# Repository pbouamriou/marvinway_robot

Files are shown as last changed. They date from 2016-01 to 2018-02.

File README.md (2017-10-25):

# marvinway
Source du projet Marvin Way (le segway depressif O_o)

## Arborescence ##

### brain ###

Projet de la carte de contrôle Haut niveau de Marvin

### control

Projet pour la carte de contrôle des moteurs

### docs

Contient la documentation globale du projet

### experience

Contient les exemples des expériences associés au projet marvinway

### meca

Contient la conception mecanique de Marvin

### shield

Projet permettant la communication entre le Brain et le reste du monde (la moelle epinière en soit)

### supply

Projet de gestion de l'alimentation

### utils

Contient des librairies utils ou des ensembles de configurations

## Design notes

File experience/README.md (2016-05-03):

# marvinway
Source du projet Marvin Way (le segway depressif O_o)

## Programme de test ##

### Installation de la chaine de compilation Teensy ###

Suivre les instructions [Débuter avec teensy](https://openclassrooms.com/courses/debuter-dans-l-informatique-embarquee-avec-teensy).

Installer tout de meme la toolchain Arduino dans le répertoire /opt car ça permettra à cmake de trouver automatiquement la toolchain.

### Installation de teensy_loader_cli

Pour permettre à cmake d'installer votre programme sur la teensy

Executez simplement les commandes suivantes depuis le dépot marvin

_Installation de teensy_loader_cli
~~~{.sh}
cd src/teensyLoaderCli/
chmod 755 teensyLoaderCli.sh # si nécéssaire
./teensyLoaderCli.sh
~~~

### Compilation ###

_Compilation du programme de test blink sous linux_

~~~{.sh}
cd src/test_blink
./configure
(cd build && cmake )
~~~

Voila c'est compilé, un fichier blink.hex est disponible sous build/blink

il est meme possible de produire et installer le programme grâce à cmake (programme test_blink par example) :

~~~{.sh}
cd src/test_blink
./configure
(cd build && cmake blink-upload )
~~~

### Test du programme ###

Suivre les memes instructions décrites par le site [Débuter avec teensy](https://openclassrooms.com/courses/debuter-dans-l-informatique-embarquee-avec-teensy).

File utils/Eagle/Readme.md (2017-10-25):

# Configuration de Eagle

## Ajouter une librairie

- Aller dans le `Control Panel -> Directories`
   ControlPanel
- Dans le premier champ ajouter le répertoire où se trouve les librairies
  (Le répertoire Libs contient des exemples de librairies utilisées dans des projets de Marvin)
- Pour Utiliser la librairie dans Eagle 
  - Il faut l'activer en affichant la liste `Libraries`

  - Cliquez droit sur la librairie Sparkfun puis appuyez sur use all

    Utilisation d'une librairie

## Configurer l'interface de création de la carte

Depuis l'interface de création de carte (board)  cliquez sur l'icones de script scr puis chargez le fichiers ConfigurationScript/spk.scr

## Informations Utiles

### Design Rule Check

Pour vérifier que la carte conçu respecte les bonnes pratiques de l'imprimeur il faut utiliser les Design Rules du constructeur. Sparkfun fourni ses propres règles de design de cartes  vous pouvez les trouver dans le répertoire EagleDesignRules.

Pour charger les règles de design il faut appuyer sur l'icône DRC icon DRC icon une interface va apparaitre appuyer sur Load

DRC

### Synchronisation entre schéma et board

Pour conserver la synchronisation entre le fichier board et le fichier schematic penser à bien les garder ouvert en même temps

## Sources

https://github.com/sparkfun/SparkFun-Eagle-Libraries

https://learn.sparkfun.com/tutorials/how-to-install-and-setup-eagle

https://learn.sparkfun.com/tutorials/using-eagle-schematic

https://learn.sparkfun.com/tutorials/using-eagle-board-layout

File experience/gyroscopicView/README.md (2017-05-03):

# gyroscopic view  
Affiche une vue openGL simple représentant l'orientation du gyroscope en tant réell

## Installation de l'environnement

### Sur Debian

~~~{.sh}
sudo apt-get install cmake libgl1-mesa-dev libglu1-mesa-dev freeglut3-dev libxmu-dev libxi-dev doxygen libboost-dev python-pip python-empy
sudo pip install -U catkin_pkg
git clone https://gicd catkin/thub.com/ros/catkin.git
cd catkin && mkdir build && cd build && cmake ../ && make && sudo make install && cd ..
git clone https://github.com/wjwwood/serial.git && cd serial
make
make install
cd ..
~~~

## Branchement de la carte Arduino au MPU_6050

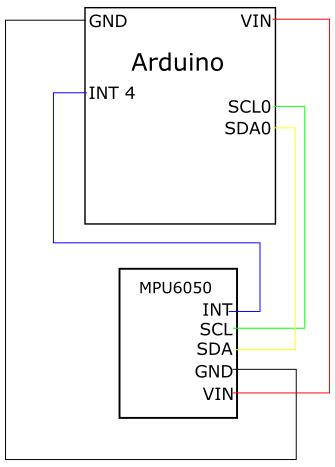
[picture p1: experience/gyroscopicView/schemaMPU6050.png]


## Calibrage du MPU_6050 ##

### Compilation et upload du programme de calibrage
~~~{.sh}
cd src/mpu6050/
make
cd build/MPU6050_Calibration/
make calibration-upload
~~~

Pensez à appuyer sur le bouton de votre arduino après le "make upload" pour bien uploader le programme

### Execution du programme de calibrage
Connectez vous au port série de la teensy pour qu'elle se calibre
Avant le calibrage vérifiez que le MPU6050 est bien à plat et ne touchez plus à la table

~~~{.sh}
cu -l /dev/ttyACM0 -s 9600
~~~
La calibration peut prendre un peu de temps.
une fois la calibration terminée reportez les valeurs dans le programme MPU6050_DOF

### Modification de l'offset dans MPU6050_DMP6
Modifier le fichier "MPU6050_DMP6/MPU6050_DMP6.ino" avec les valeurs suivantes qui se trouvent environ ligne 200
~~~{.cpp}
mpu.setXGyroOffset(27);                                                                                      
mpu.setYGyroOffset(7);
mpu.setZGyroOffset(2);
mpu.setZAccelOffset(1340); // 1688 factory default for my test chip
~~~

## Compilation et Upload du programme pour récupérer les angles d'eulers
~~~{.sh}
cd src/mpu6050
make
cd build/MPU6050_DMP6/
make mpu6050-upload
~~~

Pensez à appuyer sur le bouton de votre arduino après le "make upload" pour bien uploader le programme

## Compilation et lancement l'affichage gyroscopic

~~~{.sh}
cmake .
cd src/gyroscopicView
make
cd build/
./gyroscopicView
~~~

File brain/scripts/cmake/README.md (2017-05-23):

# Teensy CMake

## Informations
Cette toolchain est compatible avec Arduino 1.8.2 et teensyduino 1.36.

Ce projet est conçus pour être utilisé en tant que [sous module git](https://git-scm.com/book/fr/v2/Utilitaires-Git-Sous-modules) dans votre projet.

## Prérequis
### Installer Arduino 1.8.2
Vous devez installer [Arduino 1.8.2](https://git-scm.com/book/fr/v2/Utilitaires-Git-Sous-modules)
dans **/opt/arduino/** pour que le SDK arduino ainsi la toolchain pourra détecter le SDK arduino

Si vous ne savez pas comment installer Arduino je vous conseille de suivre cette [procédure] 
(https://www.hackster.io/strasserpatrick/install-arduino-ide-1-8-2-on-linux-8ef105) fonctionnelle sous debian 8

### Installer Teensyduino 1.36
Pour installer Teensyduino v1.36 suivre la procédure décrite sur le site de 
[teensy](https://www.pjrc.com/teensy/td_download.html)

### Compiler et Installer Teensyloader
Après avoir compilé le **teensyloader_cli** copier le dans **/opt/teensyloader_cli**
ainsi la toolchain pourra détecter le teensyloader_cli

Voici les [étapes](https://github.com/PaulStoffregen/teensy_loader_cli) pour compiler **teensy_loader_cli**

## Utilisation de Teensy CMake
- Créez votre projet git
- Ajouter ce dépot en tant que sous module 

```bash
git submodule add git@gitlab.42pillistreet.com:marvin/teensy_cmake.git
```

- Créez votre fichier CMakeLists.txt

```cmake
cmake_minimum_required(VERSION 2.8)
set(CMAKE_TOOLCHAIN_FILE "${CMAKE_SOURCE_DIR}/teensy_cmake/teensy-arm.toolchain.cmake")

project(blink C CXX)

macro(use_cxx11)
  if (CMAKE_VERSION VERSION_LESS "3.1")
    if (CMAKE_CXX_COMPILER_ID STREQUAL "GNU")
      set (CMAKE_CXX_FLAGS "--std=gnu++11 ${CMAKE_CXX_FLAGS}")
    endif ()
  else ()
    set (CMAKE_CXX_STANDARD 11)
  endif ()
endmacro(use_cxx11)

use_cxx11()

set(CMAKE_RUNTIME_OUTPUT_DIRECTORY "${CMAKE_CURRENT_BINARY_DIR}/bin")
set(CMAKE_ARCHIVE_OUTPUT_DIRECTORY "${CMAKE_CURRENT_BINARY_DIR}/lib")
set(CMAKE_LIBRARY_OUTPUT_DIRECTORY "${CMAKE_CURRENT_BINARY_DIR}/lib")
set(CMAKE_MODULE_PATH ${CMAKE_MODULE_PATH} ${CMAKE_CURRENT_SOURCE_DIR}/teensy_cmake)
set(TEENSY_USB_MODE SERIAL)
add_teensy_executable(blink blink.cpp)
configure_teensy_upload(blink mk20dx256) # you must specify the sane name than the executable mk20dx256 Teensy 3.1
```

- Voici le fichier blink.cpp d'exemple

```c++
/*
  Blink
  Turns on an LED on for one second, then off for one second, repeatedly.
  Example uses a static library to show off generate_arduino_library().
 
  This example code is in the public domain.
*/
#if ARDUINO >= 100
    #include "Arduino.h"
#else
    #include "WProgram.h"
#endif

const int led = LED_BUILTIN;

void setup() {                
  pinMode(led, OUTPUT);
}

void loop() {
  digitalWrite(led, HIGH);
  delay(1000);
  digitalWrite(led, LOW);
  delay(1000);
}
```

- Initialisez votre projet puis compilez le

```bash
mkdir build
cd build
cmake ..
make
make upload
```

- Maintenant appuyez sur le bouton reset de votre teensy et voilà ! :D

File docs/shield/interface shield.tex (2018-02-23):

\documentclass[11pt]{article}
\usepackage[utf8]{inputenc}
\usepackage[T1]{fontenc}
\usepackage[francais]{babel}
\usepackage{bytefield}

\begin{document}

\title{Interface MarvinShield}

\section{Introduction}

Le FPGA est piloté en SPI.

\section{Commandes}

Il existe deux types de commandes :
\begin{itemize}
  \item une commande de lecture d'une zone mémoire,
  \item une commande d'écriture d'une zone mémoire. 
\end{itemize}

La figure suivante présente le chronogramme d'une phase de lecture.

La figure suivante présente le chronogramme d'une phase d'écriture.

\subsection{Organisation mémoire}

La carte MarvinShield organise la mémoire de la manière suivante : \\

\begin{bytefield}[endianness=big, bitwidth=1em, leftcurly=., leftcurlyspace=0pt]{32}
\bitheader{0,7,8,15,16,23,24,31} \\
\begin{leftwordgroup}{00h}
\bitbox{32}{FPGA Magic ID}
\end{leftwordgroup} \\
\begin{rightwordgroup}{Version}
\begin{leftwordgroup}{04h}
\bitbox{8}{Reserved} \bitbox{8}{Majeur} \bitbox{8}{Mineur} 
& \bitbox{8}{Revision}
\end{leftwordgroup}
\end{rightwordgroup} \\
\begin{leftwordgroup}{08h}
\wordbox[tlr]{1}{}
\end{leftwordgroup} \\
\wordbox[lr]{2}{FPGA Desc} 	\\
\wordbox[blr]{1}{} \\
\begin{rightwordgroup}{Capabilities}	
\begin{leftwordgroup}{18h}
\bitbox{16}{Capability (1)} \bitbox{16}{Capability (2)}
\end{leftwordgroup} \\
\wordbox{6}{$\cdots$} \\
\begin{leftwordgroup}{38h}
\bitbox{16}{Capability (15)} \bitbox{16}{Capability (16)}
\end{leftwordgroup}
\end{rightwordgroup} \\
\begin{leftwordgroup}{3Ch}
\wordbox{1}{First device address}
\end{leftwordgroup}
\end{bytefield}

Tous les champs
Le champ "FPGA Magic ID" est toujours positionné par la shield  

\subsection{Capacités du FPGA}

\begin{bytefield}[endianness=little,bitwidth=2.2em]{16}
\bitheader{0-15} \\ 
\bitbox{3}{device ID} \bitbox{3}{device version} \bitbox{10}{Offset in memory} \\
\end{bytefield}

La liste des différents périphériques sont :
\begin{itemize}
\item PWM, valeur 01h
\item ADC, valeur 02h
\item GPIO, valeur 03h
\end{itemize}

Le champ "Offset in memory" défini l'adressage du périphérique à partir de l'adresse 3Ch.

\end{document}

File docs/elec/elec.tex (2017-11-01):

\documentclass[10pt,a4paper]{article}
\usepackage[utf8]{inputenc}
\usepackage[french]{babel}
\usepackage[T1]{fontenc}
\usepackage{amsmath,amsfonts,amssymb}
\usepackage[squaren, Gray, cdot]{SIunits}
\usepackage{tikz}
\usepackage{circuitikz}
\usepackage[left=2cm,right=2cm,top=2cm,bottom=2cm]{geometry}
\usepackage{url}

\tikzset{
xmin/.store in=\xmin, xmin/.default=-3, xmin=-3,
xmax/.store in=\xmax, xmax/.default=3, xmax=3,
ymin/.store in=\ymin, ymin/.default=-3, ymin=-3,
ymax/.store in=\ymax, ymax/.default=3, ymax=3,
}
% Commande qui trace la grille entre (xmin,ymin) et (xmax,ymax)
\newcommand {\grille}
{\draw[help lines] (\xmin,\ymin) grid (\xmax,\ymax);}
% Commande \axes
\newcommand {\axes} {
\draw[->] (\xmin,0) -- (\xmax,0);
\draw[->] (0,\ymin) -- (0,\ymax);
}
% Commande qui limite l'affichage à (xmin,ymin) et (xmax,ymax)
\newcommand {\fenetre}
{\clip (\xmin,\ymin) rectangle (\xmax,\ymax);} 
 
\begin{document}{\bf Cours d'electronique} 

\section{Circuit série et U=RI}
Dans un circuit la tension (U exprimée en \volt ) est égale à la résistance (R exprimée en \ohm) multiplié par l'intensité (I exprimée en \ampere) ce qui donne l'équation~\eqref{uri}
\begin{equation}
U=R*I
\label{uri}
\end{equation}

Remarque en série les résistances s'additionnent.

Prenons un circuit avec les résistances R1= 5 \ohm, R2= 20 \ohm, R3= 30 \ohm
\shorthandoff{:!}
\begin{figure}[h!]
  \begin{center}
    \begin{circuitikz}
      \draw (0,0)
      to[V,v=$U_q$] (0,2) % The voltage source
      to[R=$R_1$,v_<=$U_1$] (2,2) % R1
      to[R=$R_2$,v_<=$U_2$] (4,2) % R2
      to[R=$R_3$,v_<=$U_3$] (6,2) % R3
      to[short,i=$i$] (6,0)
      to[short] (0,0);
    \end{circuitikz}
    \caption{Circuit simple.}
  \end{center}
\end{figure}

Remarque en série les résistances s'additionnent.
\begin{align}
R_t &=R_1+R_2+R_3 \\
    &=5+20+30 \\
    &=55 \ohm
\end{align}

\begin{align}
I&=\frac{U}{R} \\
I&=\frac{12}{55} \\
I&=0,218 \ampere \\
\end{align}
La loi d'additivité des tensions se vérifie donc 
\begin{align}
U1&=5*0,218=1,09 \volt \\
U2&=20*0,218=4,36 \volt \\
U3&=30*0,218=6,54 \volt \\
U_q&=U1+U2+U3~=12 \volt
\end{align}

\pagebreak 

\section{Circuit Parellèle et Conductance}
La conductance est l'inverse de la résistance $ C= \frac{1}{Rt} $

\shorthandoff{:!}
\begin{figure}[h!]
  \begin{center}
    \begin{circuitikz}
      \draw (0,0)
      to[V,v=$U_q$] (0,5) % The voltage source
      to[short] (4,5)
      to[short,i_=$i_t$] (4,4)
      (4,4) to[short,i_=$i_1$] (3,4)
      to[short] (3,3)
      (4,4) to[short,i_=$i_2$] (5,4)
      to[short] (5,3)
      (3,3) to[R=$R_1$,v_<=$U_1$] (3,2) % R1
      to[short] (3,1)
      (5,3) to[R=$R_2$,v_<=$U_2$] (5,2) % R2
      to[short] (5,1)
      (3,1) to[short] (4,1)
      (5,1) to[short] (4,1)
      to[short] (4,0)
      to[short] (0,0);
    \end{circuitikz}
    \caption{Conductance d'un circuit parallèle.}
  \end{center}
\end{figure} 

R1 = 50 \ohm R2 = 30 \ohm

Pour ce circuit la conductance $ C = \frac{1}{R1}+\frac{1}{R2} = \frac{1}{50}+\frac{1}{30} = \frac{8}{150} $
Ce qui nous donne $R_t=\frac{150}{8} = 18,75 \ohm $ 

Ici on voit que la résistance totale de notre circuit parallèle est inférieur à la plus petite des résistances.

Si on calcule $i_1=\frac{U_1}{R_1}=\frac{12}{50}=0,24 \ampere $ $i_2=\frac{U_2}{R_2}=\frac{12}{30}=0,4 \ampere $

Si on compare a la résistance totale $I=\frac{12}{18,75}=0,64 \ampere$ nos deux intensités sont bien égales. 

\section{la Puissance}

La puissance P est exprimée en \watt elle se calcule à l'aide de la tension et de l'intensité utilisé par le circuit $P=U*I$.

\begin{figure}[h!]
  \begin{center}    
    \begin{circuitikz}
      \draw (0,0)
      to[V,v=$U_g$] (0,2) % The voltage source
      to[R=$R_i$,v_<=$U_i$] (2,2) % R1
      to[R=$R$,v_<=$U$] (2,0) % R2
      to[short] (0,0);
    \end{circuitikz}
    \caption{Voici mon radiateur.}
  \end{center}
\end{figure}

$R_i$ représente la résistance interne du générateur.    

$R_i=1 \ohm$ et $R = 20 \ohm$

Pour obtenir la puissace fournie par le générateur $P_f$ il faut calculer la somme des résistances $R_t= \sum R = R_i+R=1+20=21 \ohm$

avec $U=R \times I$ on peut déduire que $P=U \times I=R \times I^2=\frac{U^2}{R}$ 

on peut donc déduire directement la puissance fournie par le générateur en utilisant $P_f=\frac{U_g^2}{R}=\frac{12^2}{21}=6,857 \watt$

La puissance utile $P_u$ représente la puissance réellement utilisée est la puissance utilisé par la résistance. Pour cela il faut connaitre le courant utilisé par le circuit $I=\frac{U}{R_t}=\frac{12}{21}=0,571 \ampere$

ce qui nous donne $P_u =R \times I^2=20 \times 0,571^2=6,520 \watt$

on peut donc déduire le rendement de notre résistance $R=\frac{P_u}{P_f}=\frac{6,520}{6,857}=0,985$

\pagebreak

\section{Le condensateur}
Le condensateur est un composant qui se charge lorsqu'il est traversé par du courant jusqu'à ce qu'il ait atteint sa capacité maximal. La capicé d'un condensateur est exprimée en Farad (\farad).

Il est composé de lamelle et d'un espace vide entre elle
\begin{figure}[h!]
  \begin{center}
    \begin{circuitikz}
        \draw (0,0) 
        to node[below,pos=2]{$+q$} node[above,pos=2]{$+$} (0.5,0) 
        to [C, l^=$C$] (2.5,0) 
        to node[below,pos=-1]{$-q$} node[above,pos=-1]{$-$} (3,0) ;
    \end{circuitikz}
    \caption{Schéma d'un condensateur.}
  \end{center}
\end{figure}

Lorsque le courant $i_1$ traverse un condensateur les electrons s'accumulent sur lamelle représenté par $-q$ tandis que l'autre lamelle elle se débarrassent de ses électrons. Au fur et à mesure le courant décroit jusqu'à être nul. À ce moment notre condensateur à atteint sa pleine capacité. il va donc falloir le décharger pour pouvoir faire passer un nouveau courant.

\begin{figure}[h!]
  \begin{center}
    \begin{circuitikz}
        \draw (0,0)
        to[V,v=$U_g$] (0,2) % The voltage source
        to[short] (2,2)
        to[lamp] (4,2)
        to[C,v_<=$U_c$,i^>=$i_c$,l^=$C$] (4,0)
	to[short] (0,0)
	(2,2) to[short] (2,1); 
    \end{circuitikz}
    \caption{Circuit de charge.}
  \end{center}
\end{figure} 

Durant la charge la lampe va s'allumer puis l'intensité dans le circuit va décroite au fur et a mesure que le condensateur se charge.
Jusqu'à ce qu'elle s'éteigne une fois le condensateur complètement chargé. La tension du condensateur est alors maximal voir Figure~\ref{courbeCondensateur} p~\pageref{courbeCondensateur}
\begin{figure}[h!]
  \begin{center}
    \begin{circuitikz}
        \draw (0,0)
        to[V,v=$U_g$] (0,2) % The voltage source
        to[short] (2,2)
        to[lamp] (4,2)
        to[C,v_<=$U_c$,i_<=$i_c$,l^=$C$] (4,0)
        to[short] (2,0)
	(0,0) to[short] (1,0)
        (2,2) to[short] (2,0);
    \end{circuitikz}
    \caption{Circuit de décharge.}
  \end{center}
\end{figure}

Lors de la décharge on s'aperçoit que le courant est inversé voir Figure~\ref{courbeCondensateur} p~\pageref{courbeCondensateur}. Le phénomène est dû au fait que les électrons sont attirés par l'autre lamelle. lors de leur parcourt du circuit ils vont donc allumer la LED jusqu'à temps que le condensateur soit vide. 

Durant la décharge on observe que la tension du condensateur diminue Figure~\ref{courbeCondensateur} p~\pageref{courbeCondensateur}.
\begin{figure}
   \begin{center}
      \begin{tikzpicture}[xmin=0,xmax=16,ymin=-5,ymax=5]
   	  \axes
   	  %\draw [very thin, gray] (0,0) grid[step=0.2] (4.4,4.2);
   	  \draw[color=red] [domain=0:8, smooth] plot (\x,{4/(\x+1)-0.4});
   	  \draw[color=blue] [domain=0:8, smooth] plot (\x,{(4/(-\x-1)+4)});
          \draw[color=blue] [domain=8:16, smooth] plot (\x,{4/(\x-7)-0.4});
          \draw[color=red] [domain=8:16, smooth] plot (\x,{(4/(-\x+7)+0.4)});
	  \draw[color=blue] (0,5) node [right] {$U(\volt)$};
	  \draw[color=red] (0,5) node [left] {$I(\ampere)$};
   	  \draw (16,0) node [below] {t};
   	  \draw (0,0) node [below left] {O};
   	  \fill[color=green!70, opacity=0.5] (0,-0.1) rectangle (8,0.1);
   	  \draw (4,0) node [below] {$charge$};
	  \fill[color=yellow!70, opacity=0.5] (8,-0.1) rectangle (16,0.1);
          \draw (12,0) node [below] {$decharge$};
       \end{tikzpicture}
       \caption{Courbe d'intensité de charge}
       \label{courbeCondensateur}
   \end{center}
\end{figure} 

\section{Le transistor MOFSET}

Le Mofset est un transistor différent du transistor bipolaire car il est piloté en tension (le bipolaire étant piloté en courant). De plus le transistor MOFSET
consomme peu d'énergie (du moins quand il est pas sans cesse en commutation).
En mode non commuté, il se comporte comme une résistance variable.

Le transistor MOFSET existe en 4 déclinaisons :
\begin{itemize}
  \item Le MOFSET à canal N à enrichissement (Figure \ref{mofsetNenri}). Lorsque la tension $V_{TH}$ est suppérieure au seuil $V_{TH}$, le MOFSET est passant.
  \item Le MOFSET à canal P à enrichissement (Figure \ref{mofsetPenri}). Lorsque la tension $V_{TH}$ est inférieure au seuil $V_{TH}$ ($V_{TH}$ étant une tension négative), le MOFSET est passant.
  \item Le MOFSET à canal N à appauvrissement (Figure \ref{mofsetNappau}). Lorsque la tension $V_{TH}$ est inférieur au seuil $V_{TH}$, le MOFSET est passant.
  \item Le MOFSET à canal P à appauvrissement (Figure \ref{mofsetPappau}). Lorsque la tension $V_{TH}$ est suppérieure au seuil $V_{TH}$ ($V_{TH}$ étant une tension négative), le MOFSET est passant.
\end{itemize}

\begin{figure}
   \begin{center}
      \begin{circuitikz}
      % Equivalent circuit:
         \begin{scope}[scale=0.8]
            \draw (0,0) to[Tnigfete,n=mosn] (0,2);
         \end{scope}
      \end{circuitikz}
      \caption{Mofset à canal N à enrichissement}
      \label{mofsetNenri}
   \end{center}
\end{figure}

\begin{figure}
   \begin{center}
      \begin{circuitikz}
      % Equivalent circuit:
         \begin{scope}[scale=0.8]
            \draw (0,0) to[Tpigfete,n=mosp] (0,2);
         \end{scope}
      \end{circuitikz}
      \caption{Mofset à canal P à enrichissement}
      \label{mofsetPenri}
   \end{center}
\end{figure}

\begin{figure}
   \begin{center}
      \begin{circuitikz}
      % Equivalent circuit:
         \begin{scope}[scale=0.8]
            \draw (0,0) to[Tnigbt,n=mosn] (0,2);
         \end{scope}
      \end{circuitikz}
      \caption{Mofset à canal N à appauvrissement}
      \label{mofsetNappau}
   \end{center}
\end{figure}

\begin{figure}
   \begin{center}
      \begin{circuitikz}
      % Equivalent circuit:
         \begin{scope}[scale=0.8]
            \draw (0,0) to[Tpigbt,n=mosp] (0,2);
         \end{scope}
      \end{circuitikz}
      \caption{Mofset à canal P à appauvrissement}
      \label{mofsetPappau}
   \end{center}
\end{figure}

Les MOFSETS sont souvent utilisés pour commuter des circuits de plusieurs ampères. On nomme ces MOFSETS, MOFSETS de puissance.
Malheureusement ces MOFSETS ne sont pas totallement adaptés aux micro-controlleurs, car les niveaux logiques des micro-controlleurs sont plus bas que ceux des MOFSETS
de puissance. Cela à pour conséquence, de ne pas faire fonctionner le MOFSET en mode commuté. Ainsi, la résistance aux bornes du MOFSET ($RDS_{on}$) n'est pas au plus bas.

C'est pour cette raison qu'une famille de MOFSET a été créer pour s'adapter aux niveaux logiques des micro-controlleurs. Cette famille se nomme «logic level».

Une autre problématique avec les transistors MOFSETS est de permettre une commutation rapide à hautes fréquences (au delà de 20kHz). Il s'avère qu'une commutation rapide
n'est possible que lorsque le circuit de commande fourni suffisement de courant pour «accélérer la commutation». Bien souvent les circuits de commande sont des
micro-controlleurs qui ne permettent pas fournir le courant demandé par le transistor. La commutation est alors ralenti.

Le schéma \ref{driverInverseur} présente le moyen de piloter un mofset mais avec une logique inverse. L'avantage de ce schéma est d'etre beaucoup plus simple à comprendre.

\begin{figure}
   \begin{center}
      \begin{circuitikz}
      % Equivalent circuit:
         \begin{scope}[scale=0.8]
            \draw
            (0,0) node[left]{PWM} to[short,o-](1,0)
            to[R,l=R1] (3,0)
            to[short] (4,0)
            to node[pnp,anchor=B]{} (5,0);
         \end{scope}
      \end{circuitikz}
      \caption{Driver de MOFSET en mode inverseur}
      \label{driverInverseur}
   \end{center}
\end{figure}

\section{Les Bobines}

Les bobines (appelées aussi autoinductances, solénoïde ou self) est constitué d'un enroulement de fil conducteur éventuellement autour d'un noyau en matériau férromagnétique \cite{BobineWiki}.

à compléter
- Pilotage de courant 
- Filtre

\section{les moteurs}
\subsection{Introduction}

Il existe différents types de moteur (thermique, electrique, stirling...), cette section va se concentrer sur les moteur électriques plus précisément les moteurs à courant continu.

Un moteur permet de transformer l'énergie électrique en énergie mécanique. l'avantage du moteur électrique par rapport a un moteur thermique est que sont rendement est bien meilleur (de l'ordre de 80% pour un moteur électrique contre 40%). Cependant malgré un très bon rendement  

\subsection{À quoi ça sert un moteur ?}

Il s'agit d'un composant de \textbf{conversion d'énergie électrique en énergie mécanique de rotation}. A contrario une dynamo fonctionne sur le principe d'un moteur inversé puisqu'il s'agit d'un composant de conversion d'énérgie mécanique en énergie électrique.

\subsection{Comment fonctionne un moteur à courant continu?}

Un moteur CC (moteur à courant continu) est composé d'un \textbf{stator} et d'un \textbf{rotor} (c'est une simplification de la réalité il y a quelques autres composants). 
Le \textbf{stator} est composé de deux ou plus de bobines fixées à la carcasse du moteur, lorsque les bobines vont être traversées par un courant elles vont alors exercer un champ magnétique sur le \textbf{rotor}.  

\section{Porte Logiques}

\section{Bascule R/S}

\section{NE555}

\section{Pont En H}

\subsection{Principe de fonctionnement}
Le Pont en H est un circuit qui permet de piloter la vitesse et changer le sens de rotation d'un
moteur. Le pont en H va permettre d'inverser le sens du courant qui traverse un moteur permettant
ainsi de changer son sens de rotation ou d'ajuster la quantité de courant le traversant permettant
ainsi d'ajuster sa vitesse.

\begin{figure}[!h]
   \begin{minipage}[c]{.33\linewidth}
      \centering
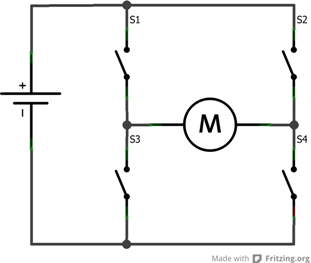
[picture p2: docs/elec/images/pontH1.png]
      
      \caption{\label{pontH1} Pont en H simple}
   \end{minipage}
   \begin{minipage}[c]{.33\linewidth}
      \centering
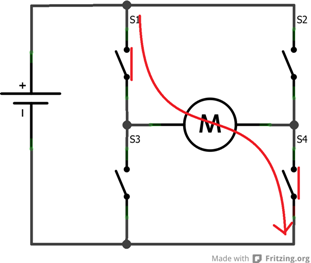
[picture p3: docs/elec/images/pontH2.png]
      
      \caption{\label{pontH2} Pont H sens 1}
   \end{minipage}
   \begin{minipage}[c]{.33\linewidth}
       \centering
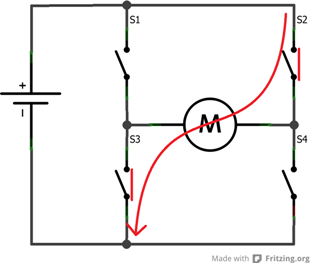
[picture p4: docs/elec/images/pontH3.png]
       
       \caption{\label{pontH3} Pont H sens2}
   \end{minipage}
\end{figure}

Dans la figure~\ref{pontH1} on retrouve un pont en H réaliser à partir de simple interrupteurs. Si
S1 et S4 (\ref{pontH2}) sont fermé en même temps le courant va parcourir le moteur dans un sens. Si S2
et S3 \ref{pontH3} sont fermé le courant va parcourir le moteur dans le sens inverse.

On peut aussi courcircuiter le moteur pour créer un phénomène de frein magnétique. Le moteur va
génerer être freiner par le courant qu'il va générer lui même. 

\begin{figure}[!h]
   \begin{minipage}[c]{.50\linewidth}
      \centering
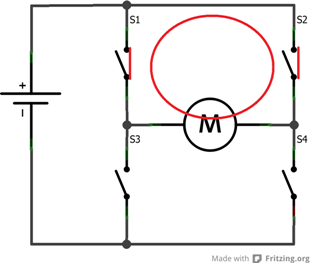
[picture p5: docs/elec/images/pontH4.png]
      
      \caption{\label{pontH4} Frein magnétique S1,S2}
   \end{minipage}
   \begin{minipage}[c]{.50\linewidth}
      \centering
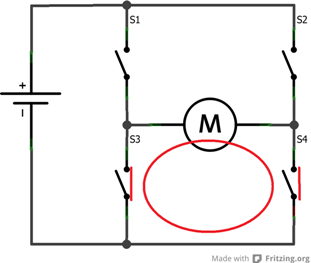
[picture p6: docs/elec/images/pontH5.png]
      
      \caption{\label{pontH5} Frein magnétique S3,S4}
   \end{minipage}
\end{figure}

Un pont En H réel n'est pas fait à partir d'interrupteur mais de transistor. Il faut savoir que
lorsque le moteur ne sera pas alimenté il va génerer un courant dit de "roue libre". Ce courant peut
abimer les transistors dans ce cas il faut le protéger pour cela on va utiliser des diodes de roues
libres.

\begin{figure}[!h]
   \centering
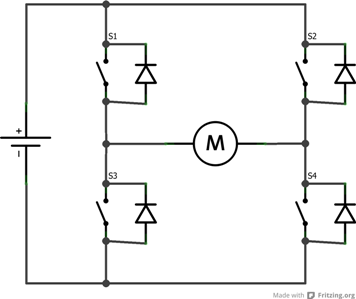
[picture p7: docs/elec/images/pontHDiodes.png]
   
   \caption{\label{pontH4} Diode de roue libre}
\end{figure}

Ainsi lorsque le moteur n'est pas alimenté le courant généré par le moteur passera dans les diodes
de roues libres	et non dans les transistors. Ce qui permet de les préserver.

\subsection{Conception Naive}

Afin de mieux apréhender le fonctionnement d'un pont en H j'ai réalisé un premier prototypes sans
utiliser un composant tout fait tel un L298

Ajouter photo proteus

À l'aide du logiciel de simulation Proteus et plusieurs prototype j'en suis arrivé au résultat
suivant : 

Puis j'ai réalisé ce prototype sur une petite carte en bakélite

Ajouter photo

\subsection{Conception d'un vrai Circuit de control Moteur}

\cite{MoteurCCEskimon}
\bibliographystyle{plain}
\bibliography{elec}

http://eskimon.fr/285-arduino-601-le-moteur-courant-continu
http://ancrobot.free.fr/Old_version/fichtech/action/ponth/index.htm
http://ancrobot.free.fr/Old_version/fichtech/action/ponthII/index.htm

\end{document}

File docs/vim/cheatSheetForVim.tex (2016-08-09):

display line numbers => :set numbers
Syntax Highlighting => :syntax on
Fix Indentation of File => ggVG (to select all file as visual) then =
Edit file specified in a new tab => :tabedit {file}
Close current tab => :tabclose
go to previous tab => gt
go to next tab => gT
go to specified tab => {i}gt
go to the end of a line => $
copy current line => yy
cut current line => dd
cut until the end of line => d$
paste current line => p

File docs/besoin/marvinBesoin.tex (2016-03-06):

\documentclass[10pt,a4paper]{article}
\usepackage[utf8]{inputenc}
\usepackage[french]{babel}
\usepackage[T1]{fontenc}
\usepackage[left=2cm,right=2cm,top=2cm,bottom=2cm]{geometry}

\begin{document}{\bf Le Besoin de Marvin} 

\section{Comment faire pour donner vie à Marvin}

\begin{itemize}
\item Mangez => Batterie
\item Digérer => Carte Puissance
\item Tenir en équilibre => Carte Moteur
\item Découvrir son environment => Carte Moteur
\item être intelligent => BeagleBone
\end{itemize}

C'est moi dany la star en électronique.
Bah non tu t'appelles philippe maintenant

\section{Détails Technique}

    \begin{itemize}
    	\item Trouver une batterie pas trop lourdes (Batterie LiPo-Succion)
    	\item Trouver ou la positionner sur le schéma mécanique
    	\item Gestion de la décharge de la batterie (LiPo-Succion Algo)
    	\item Carte de puissance: Son rôle
    	\begin{itemize}
        	\item Charger une batterie
        	\item Délivrer les différentes tensions aux différentes cartes.
        	\item Faire les mesures de courant
        	\item Gère le fait de pouvoir alimenter => v5 (surtout si c'est fait par un noob de l'électronique
    	\end{itemize}
    	\item Carte Moteurs : Son rôle
    	\begin{itemize}
        	\item Piloter les moteurs (Pont en H, piloté par la Teensy)
        	\item Filtrage de Kaalman
        	\item Controle les capteurs (Position Angulaire)
        	\item Execute les commandes envoyé par le cerveau(Vitesse RoueG, Vitesse RoueD)
        	\item Récupérer la position des roues (Optionnel parce que plus cher) => v4 (Parce que la V3 marche pas)
        	\item Autre : Trouver la réponse à la vie l'univers et tout ! => Revenez dans quelques Milliard d'années
    	\end{itemize}
    	\item  Beagleboned+Shield
    	\begin{itemize}
        	\item Envoi des consignes (ordre moteur), supervision des données remontées par les différentes cartes (gyro, charge de la batterie),
        	\item Réception des ordres d'une (Wiimote, Smartphone...)
        	\item Interface Web de Debug (
            	\begin{itemize}
            		\item Voir l'état des capteurs en live
            		\item Voir l'état des batteries
            		\item Voir l'équilibre de Marvin
            		\item Autre données intérréssantes
            		\item  Commande de Base avancer, reculer, Standby
            		\item Voir la Webcam(v3)
            	\end{itemize}
        	\item Module sonore pour faire Coin ! et autre je suis déprimé (v42)
        	\item Pilotage de deux cerveau moteur(Panen-Tilt)(v4)
        	\item Pilotage de la caméra(v3)
  	\end{itemize}
    \end{itemize}
    Détails: On alimente ls cartes moteurs et la Shield avec la carte de puissance. La beaglebone sera alimenté par la Shield
\section{Les centres d'intérets de chacun}

\begin{itemize}
\item Guy Super Canard: 
    \begin{itemize}
    \item Faire du Linux
    \item Haut Niveau (Vers l'infini et l'au delà)
    \item Il est Open (Source ?)
    \end{itemize}
\item Dany:
    \begin{itemize}
    \item bas niveau (c'est petit)
    \item Partie Bootloader (Donne des coups de pied pour démarrer)
    \item => Passe par le BUS CAN Réalisé côté Shield Le But étant de pouvoir flasher rapidement les autres carte avec une interface unique
    \end{itemize}
\item Philippe:
    \begin{itemize}
    \item Les Problèmes Et-les-Chroniques de Marvin Analogique et Numéraire (Voir Calendaire) On est pas sur le calendrier Maya il est fini
    \item Bas niveau voir proche du centre de la terre
    \end{itemize}
\item  Nicolas:
    \begin{itemize}
    \item Les problèmes ÉleChronique de Marvin (On va faire sauter les fusibles à Dany !)
    \item Filtrage de Kaalman (Mais besoin d'aide ça sembe compliqué il y a des maths)
    \end{itemize}
\end{itemize}

\section{Kifékoi}
\begin{itemize}
\item Dany : 
    \begin{itemize}
   \item Carte extension Beaglebone(Shield)
   \end{itemize}
\item Guy:
   \begin{itemize}
   \item Mettre en place un linux => BeagleBone
   \item installer un Serveur NodeJs(ou autre si tu trouve mieux) => Sur le linux Beaglebone
   \item on veut des sous Pour me soudoyer il faut minimun 20 euros et 1 Bière
   \end{itemize}
\item Philippe:
    \begin{itemize}
    \item Concevoir la carte de puissance (ça marchera du premier coup biensûr)
    \item concevoir la carte moteur
    \end{itemize}
\item Nicolas:
    \begin{itemize}
    \item Concevoir la carte de puissance et la tester (ça marchera du premier coup biensûr)
    \item Concevoir la carte Moteur
    \end{itemize}
\end{itemize}
\end{document}

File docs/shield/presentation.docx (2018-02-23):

# MarvinShield

# I. Présentation du projet :

# II. Architecture matériel du Shield :

J3

J4

J1

J2

Interface

FPGA/Servo

FPGA

J3

J4

J1

J2

J1

J2

ADC

(SPI)

Driver CAN

J5

EEPROM CFG BB

# III. Organisation interne du FPGA

# IV. Mapping mémoire

## FPGA Servo motor :

### Register Mapping :

Offset | Register | Name | Access | Reset
0x0000 | FPGA Device Magic ID | FPGA_MAGIC | Read-Only | 0x00361542
0x0004 | FPGA Firmware Version | FPGA_VERSION | Read-Only | -
0x0006 | FPGA Desc | FPGA_DESC | Read-Only
0x0016 | FPGA Capabilities | FPGA_CAPA | Read-Only
0x0040
0x0008 | Servo Motor Enable Register | SER_SER | Write-Only | -
0x000C | Servo Motor Disable Register | SER_SDR | Write -Only | -
0x0010 | Servo Motor Status Register | SER_SSR | Read-Only | 0x00000000
0x0014 | Servo Motor set-point Register Base Address | SER_RCBA | Read-Only | 0x00000028
0x0018 | Reserved | - | - | -
0x001C | Reserved | - | - | -
0x0020 | Reserved | - | - | -
0x0024 | Reserved | - | - | -
0x0028 | Servo Motor 0 Position Set-Point | SER_SP0 | Read/Write | 0x00000000
0x002C | Servo Motor 1 Position Set-Point | SER_SP1 | Read/Write | 0x00000000
0x0030 | Servo Motor 2 Position Set-Point | SER_SP2 | Read/Write | 0x00000000
0x0034 | Servo Motor 3 Position Set-Point | SER_SP3 | Read/Write | 0x00000000

FPGA Device Magic ID

Name: FPGA_MAGIC

Address: 0x0000

Access: Read-Only

31 | 30 | 29 | 28 | 27 | 26 | 25 | 24
23 | 22 | 21 | 20 | 19 | 18 | 17 | 16

MAGIC ID
15 | 14 | 13 | 12 | 11 | 10 | 9 | 8
7 | 6 | 5 | 4 | 3 | 2 | 1 | 0

• MAGIC ID [31 : 0] : FPGA Magic ID

Set to 0x00361542

FPGA Firmware Version

Name: FPGA_VERSION

Address: 0x0004

Access: Read-Only

15 | 14 | 13 | 12 | 11 | 10 | 9 | 8
| | | | MAJOR
7 | 6 | 5 | 4 | 3 | 2 | 1 | 0
MINOR | | | | REVISION

• Firmware Major version [11 : 8]

• Firmware Minor version [7 : 4]

• Firmware Revision version [3 : 0]

FPGA Desc

Name: FPGA_DESC

Address: 0x0006

Access: Read-Only

63 | 62 | 61 | 60 | 59 | 58 | 57 | 56
55 | 54 | 53 | 52 | 51 | 50 | 49 | 48
47 | 46 | 45 | 44 | 43 | 42 | 41 | 40
39 | 38 | 37 | 36 | 35 | 34 | 33 | 32
31 | 30 | 29 | 28 | 27 | 26 | 25 | 24
23 | 22 | 21 | 20 | 19 | 18 | 17 | 16
15 | 14 | 13 | 12 | 11 | 10 | 9 | 8
. | . | . | . | . | N | O | I
7 | 6 | 5 | 4 | 3 | 2 | 1 | 0
T | P | I | R | C | S | E | D

• MAGIC ID [31 : 0] : FPGA Magic ID

Set to 0x00361542

FPGA Capabilities

Name: FPGA_CAPA

Address: 0x0040

Access: Read-Only

15 | 14 | 13 | 12 | 11 | 10 | 9 | 8
7 | 6 | 5 | 4 | 3 | 2 | 1 | 0
Reserved | | | | Nb controlers

Servo Motor Enable Register

Name: SER_SER

Address: 0x0008

Access: Write-Only

31 | 30 | 29 | 28 | 27 | 26 | 25 | 24
23 | 22 | 21 | 20 | 19 | 18 | 17 | 16
15 | 14 | 13 | 12 | 11 | 10 | 9 | 8
7 | 6 | 5 | 4 | 3 | 2 | 1 | 0
| | | | CH3 | CH2 | CH1 | CH0

CH0–CH3: Servo motor channel Enable

0: No effect.

1: Enables the Servo motor channel.

Servo Motor Disable Register

Name: SER_SDR

Address: 0x000C

Access: Write-Only

31 | 30 | 29 | 28 | 27 | 26 | 25 | 24
23 | 22 | 21 | 20 | 19 | 18 | 17 | 16
15 | 14 | 13 | 12 | 11 | 10 | 9 | 8
7 | 6 | 5 | 4 | 3 | 2 | 1 | 0
| | | | CH3 | CH2 | CH1 | CH0

CH0–CH3: Servo motor channel Disable

0: No effect.

1: Disables the Servo motor channel.

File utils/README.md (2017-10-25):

# Utils
Ressources utilitaires

## Arborescence ##

### Eagle ###

Eagle contient des librairies et des scripts de configuration pour eagle

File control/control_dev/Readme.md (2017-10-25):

# Carte de développement pour le pilotage des moteurs

## Configuration

Vous devez suivre la procédure de configuration d'EAGLE décrite dans le README situé dans utils/Eagle 

Pour ajouter le projet dans Eagle :

- Aller dans le `Control Panel -> Directories`

  ControlPanel

- Dans le cinquième champs `Projects` ajouter le répertoire correspondant au répertoire parent du répertoire carte



## Sources

[add custom project folder into eagle]: http://fsdportal.com/add-custom-project-folder-eagle-control-panel/	"add custom project folder into eagle"

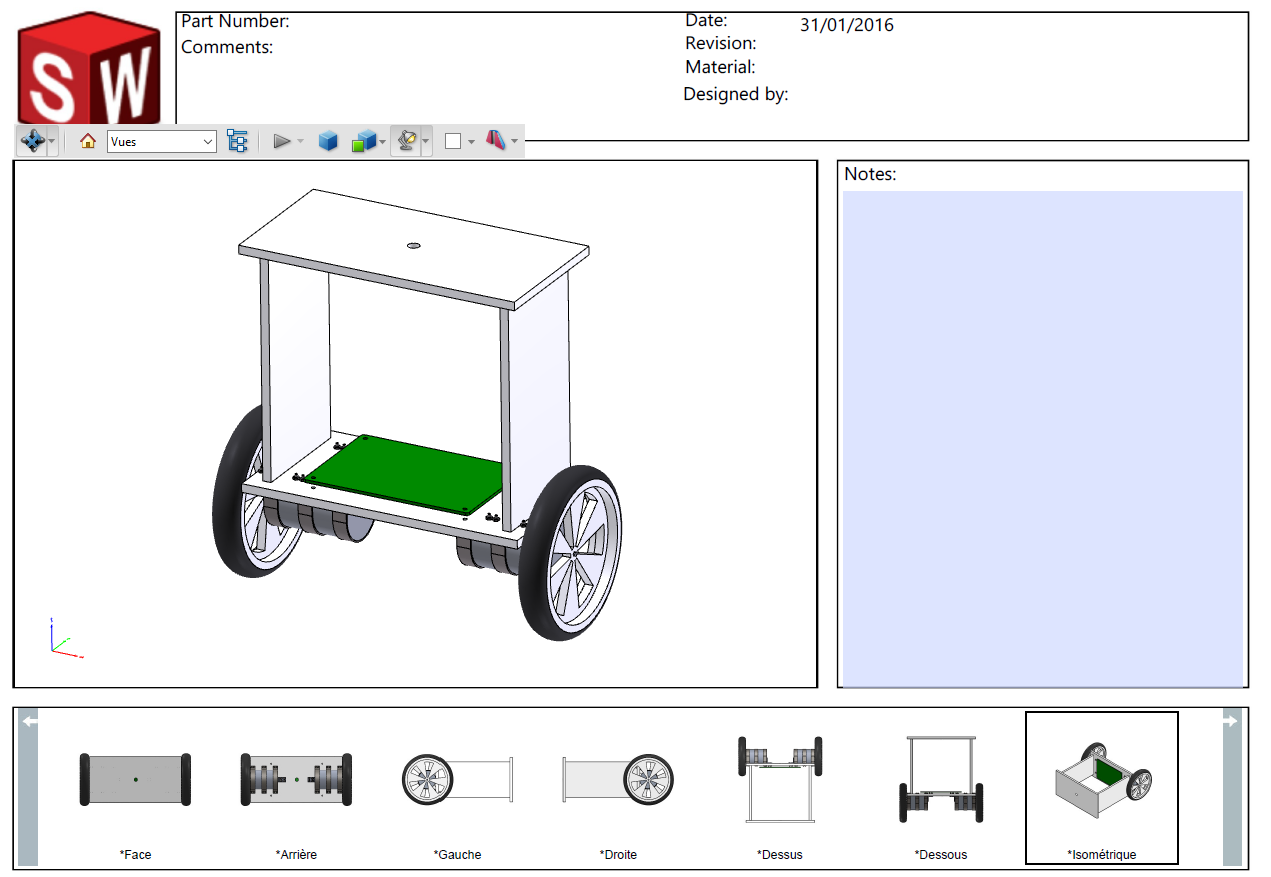
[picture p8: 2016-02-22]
experience/Marvin1.png

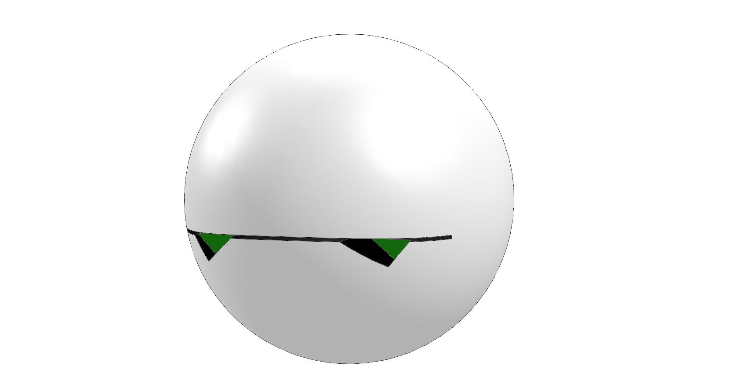
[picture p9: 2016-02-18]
meca/marvin/marvinTete.PNG

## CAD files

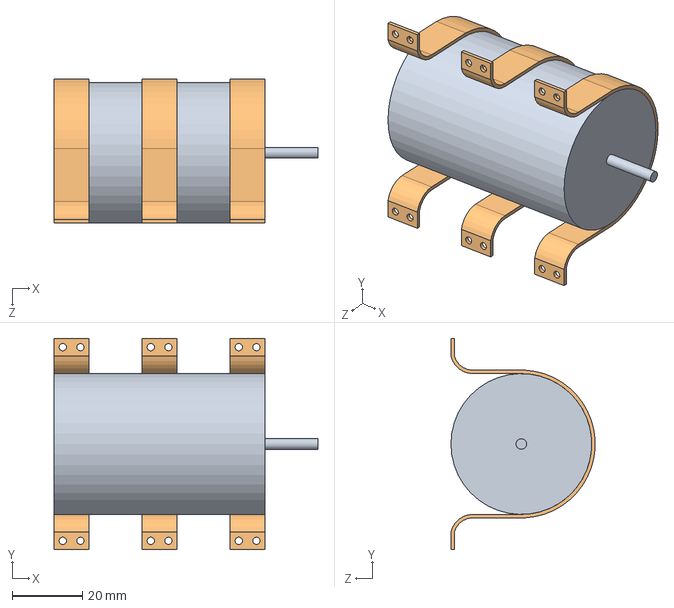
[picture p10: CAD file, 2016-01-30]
meca/pieces/moteur-fixation.SLDASM
75.0 x 60.0 x 41.0 mm
moteur40-60
fixationMoteur40-2 x 3

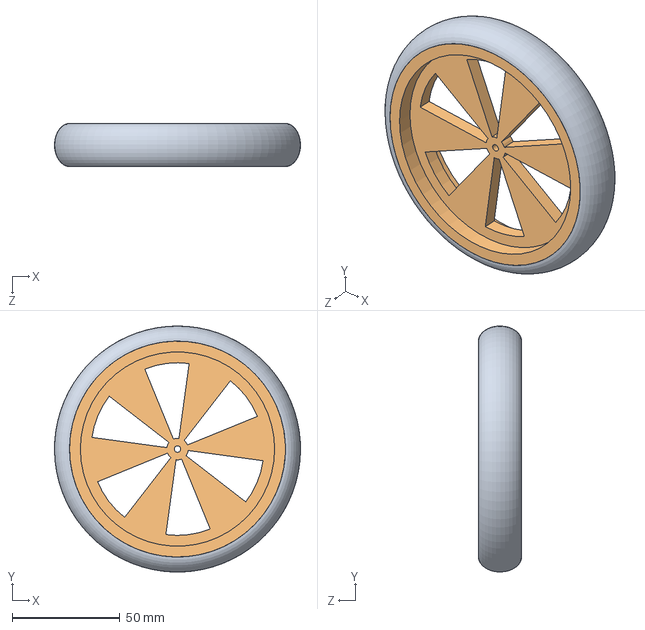
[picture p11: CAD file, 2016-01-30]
meca/pieces/roue200-2.SLDASM
114.0 x 113.9 x 20.0 mm
pneu-200-2
jante10-2

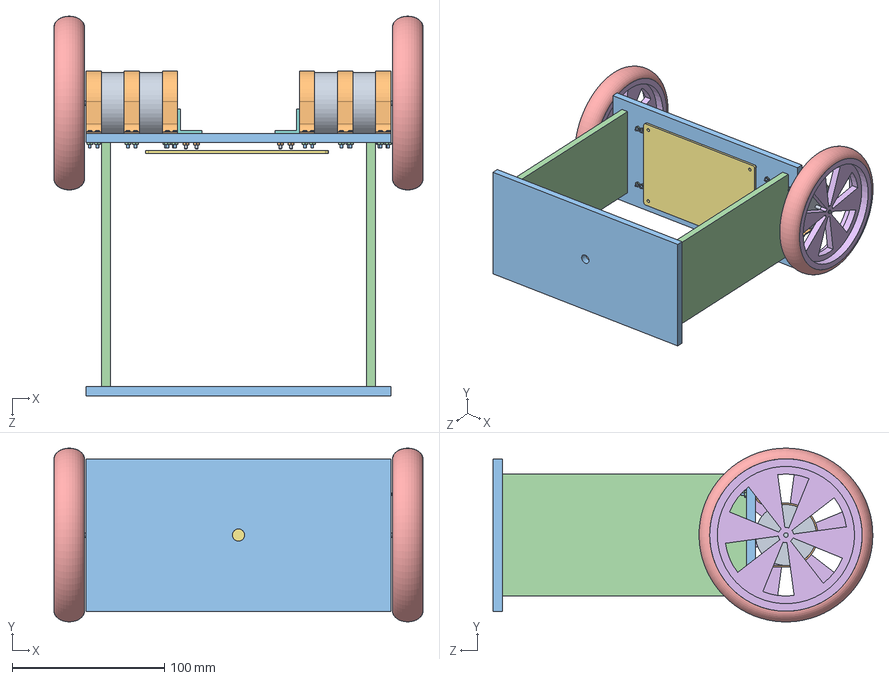
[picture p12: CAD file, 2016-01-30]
meca/pieces/marvin1.SLDASM
242.0 x 113.9 x 249.0 mm
moteur40-60 x 2
fixationMoteur40-2 x 6
plaque200-100-6 x 2
plaque160-80-6 x 2
pneu-200-2 x 2
jante10-2 x 2
carte
butee15-15 x 2
socket head cap screw_am x 8
hex nut style 1_am x 8
socket head cap screw_ai x 22
machine screw nut hex_ai x 22

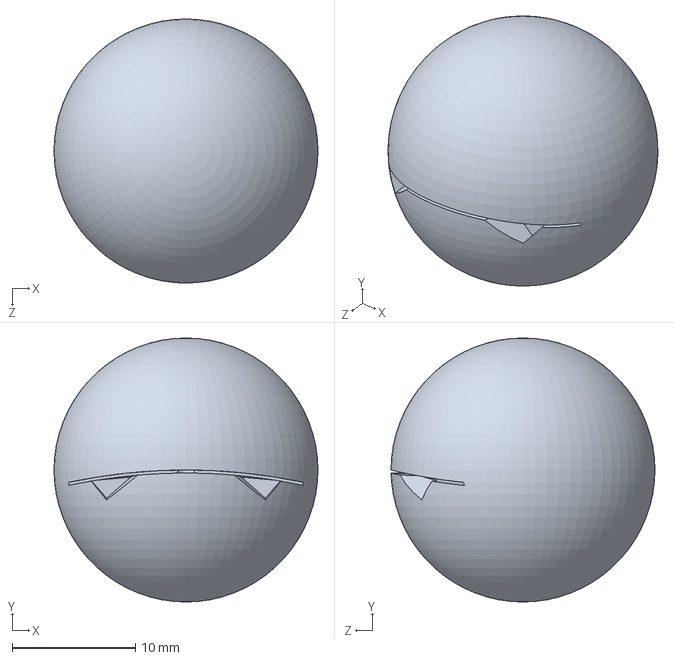
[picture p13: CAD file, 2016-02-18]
meca/marvin/marvinTete.SLDPRT
21.4 x 21.4 x 21.4 mm

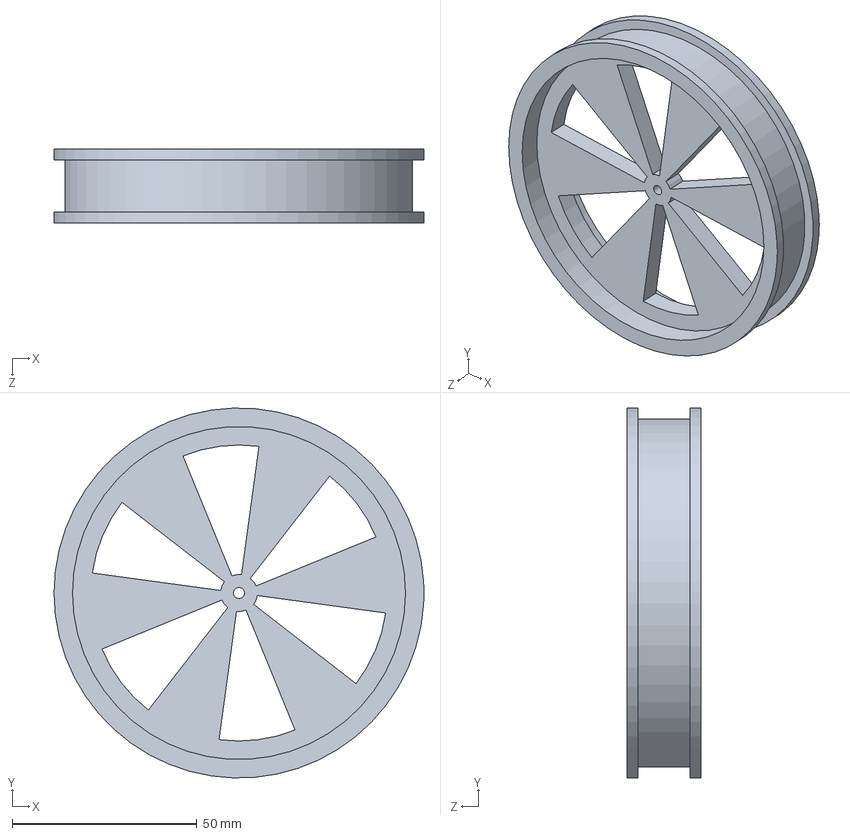
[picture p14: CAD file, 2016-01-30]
meca/pieces/jante10-2.SLDPRT
100.0 x 100.0 x 20.0 mm

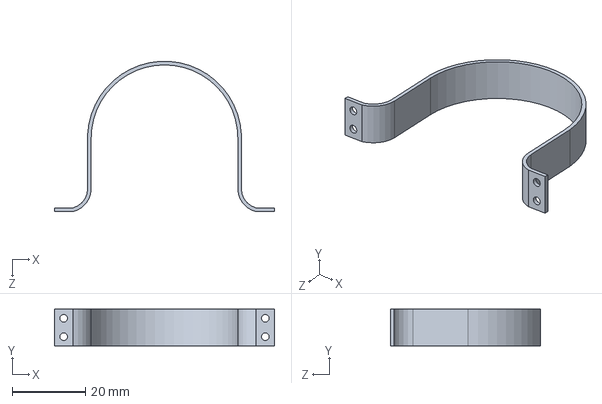
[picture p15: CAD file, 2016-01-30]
meca/pieces/fixationMoteur40-2.SLDPRT
60.0 x 10.0 x 41.0 mm

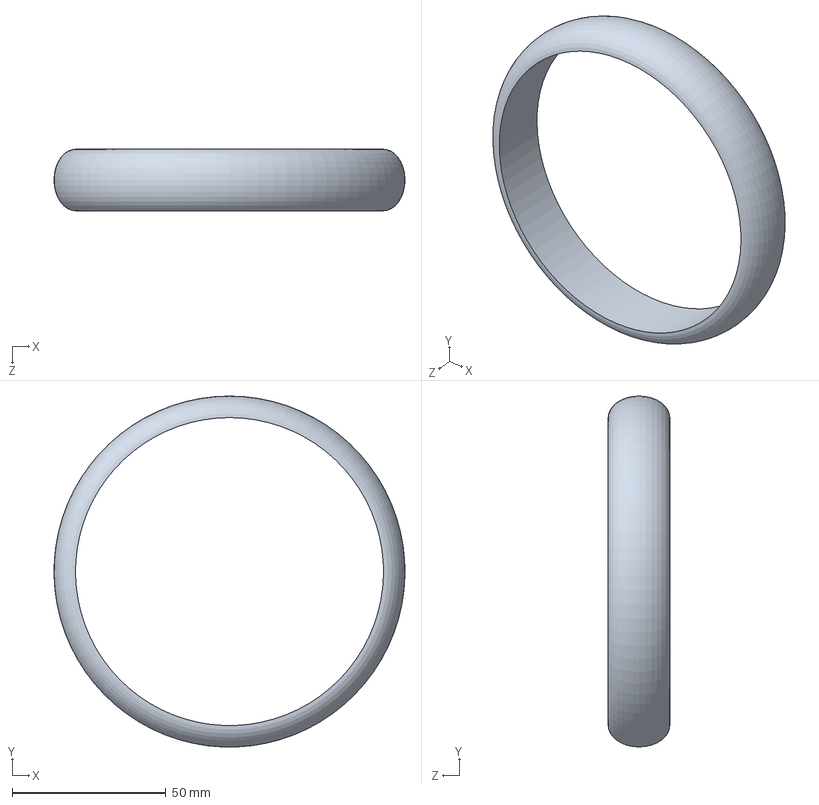
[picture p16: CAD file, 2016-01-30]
meca/pieces/pneu-200-2.SLDPRT
114.0 x 113.9 x 20.0 mm

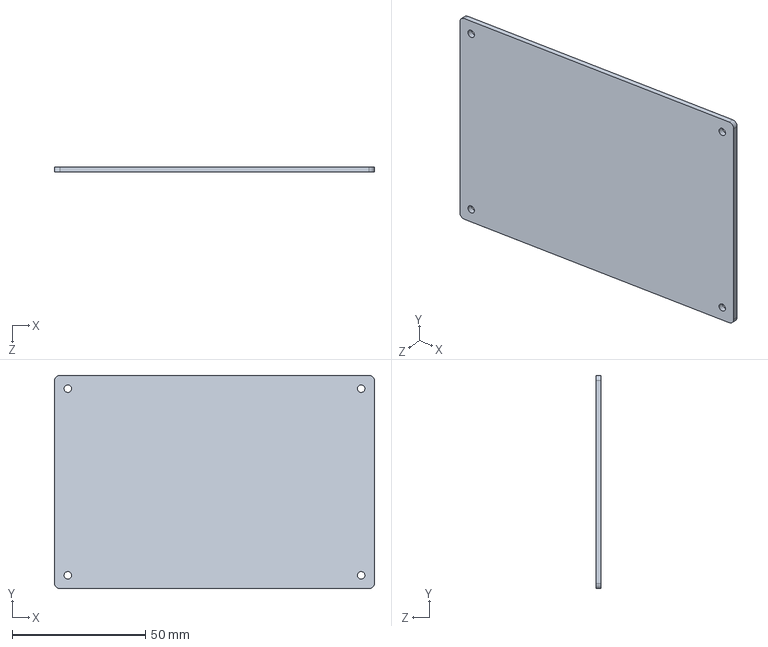
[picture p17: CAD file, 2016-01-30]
meca/pieces/carte.SLDPRT
120.0 x 80.0 x 2.00 mm

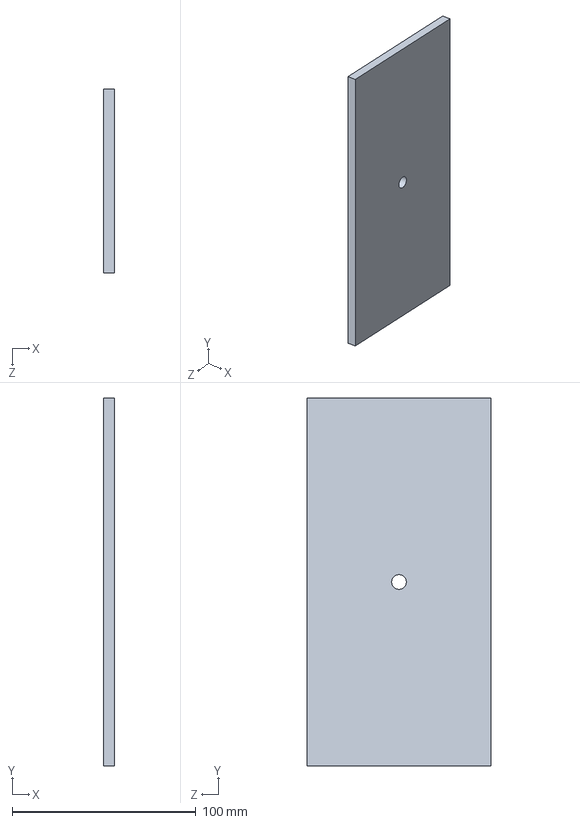
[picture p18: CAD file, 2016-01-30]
meca/pieces/plaque200-100-6.SLDPRT
6.00 x 200.0 x 100.0 mm

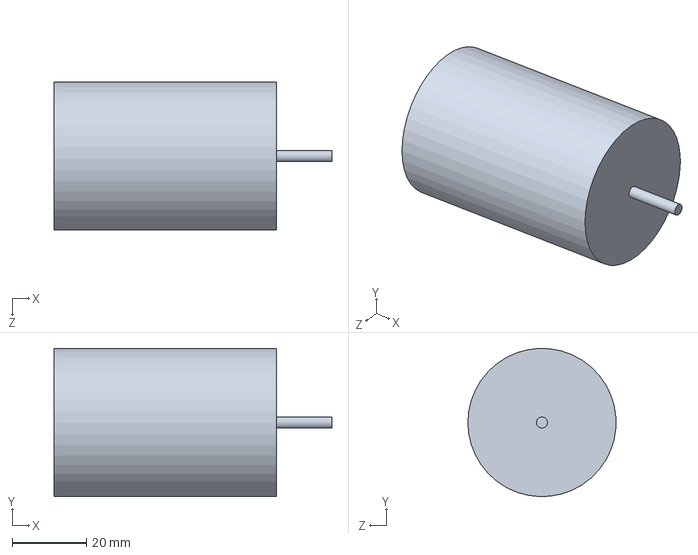
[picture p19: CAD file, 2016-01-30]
meca/pieces/moteur40-60.SLDPRT
75.0 x 40.0 x 40.0 mm

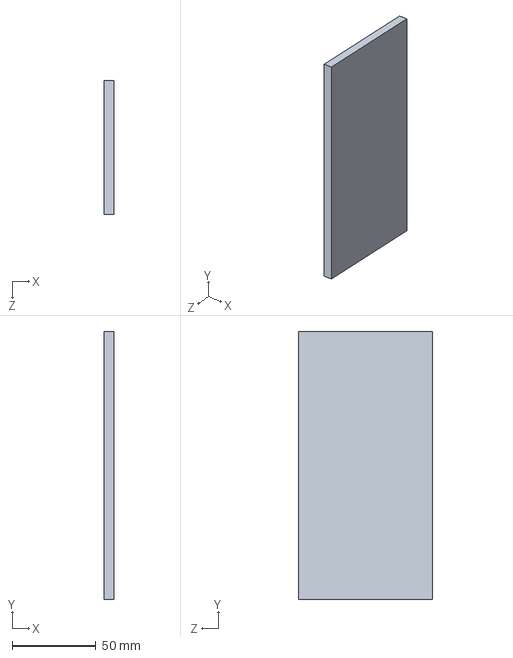
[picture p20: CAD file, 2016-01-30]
meca/pieces/plaque160-80-6.SLDPRT
6.00 x 160.0 x 80.0 mm

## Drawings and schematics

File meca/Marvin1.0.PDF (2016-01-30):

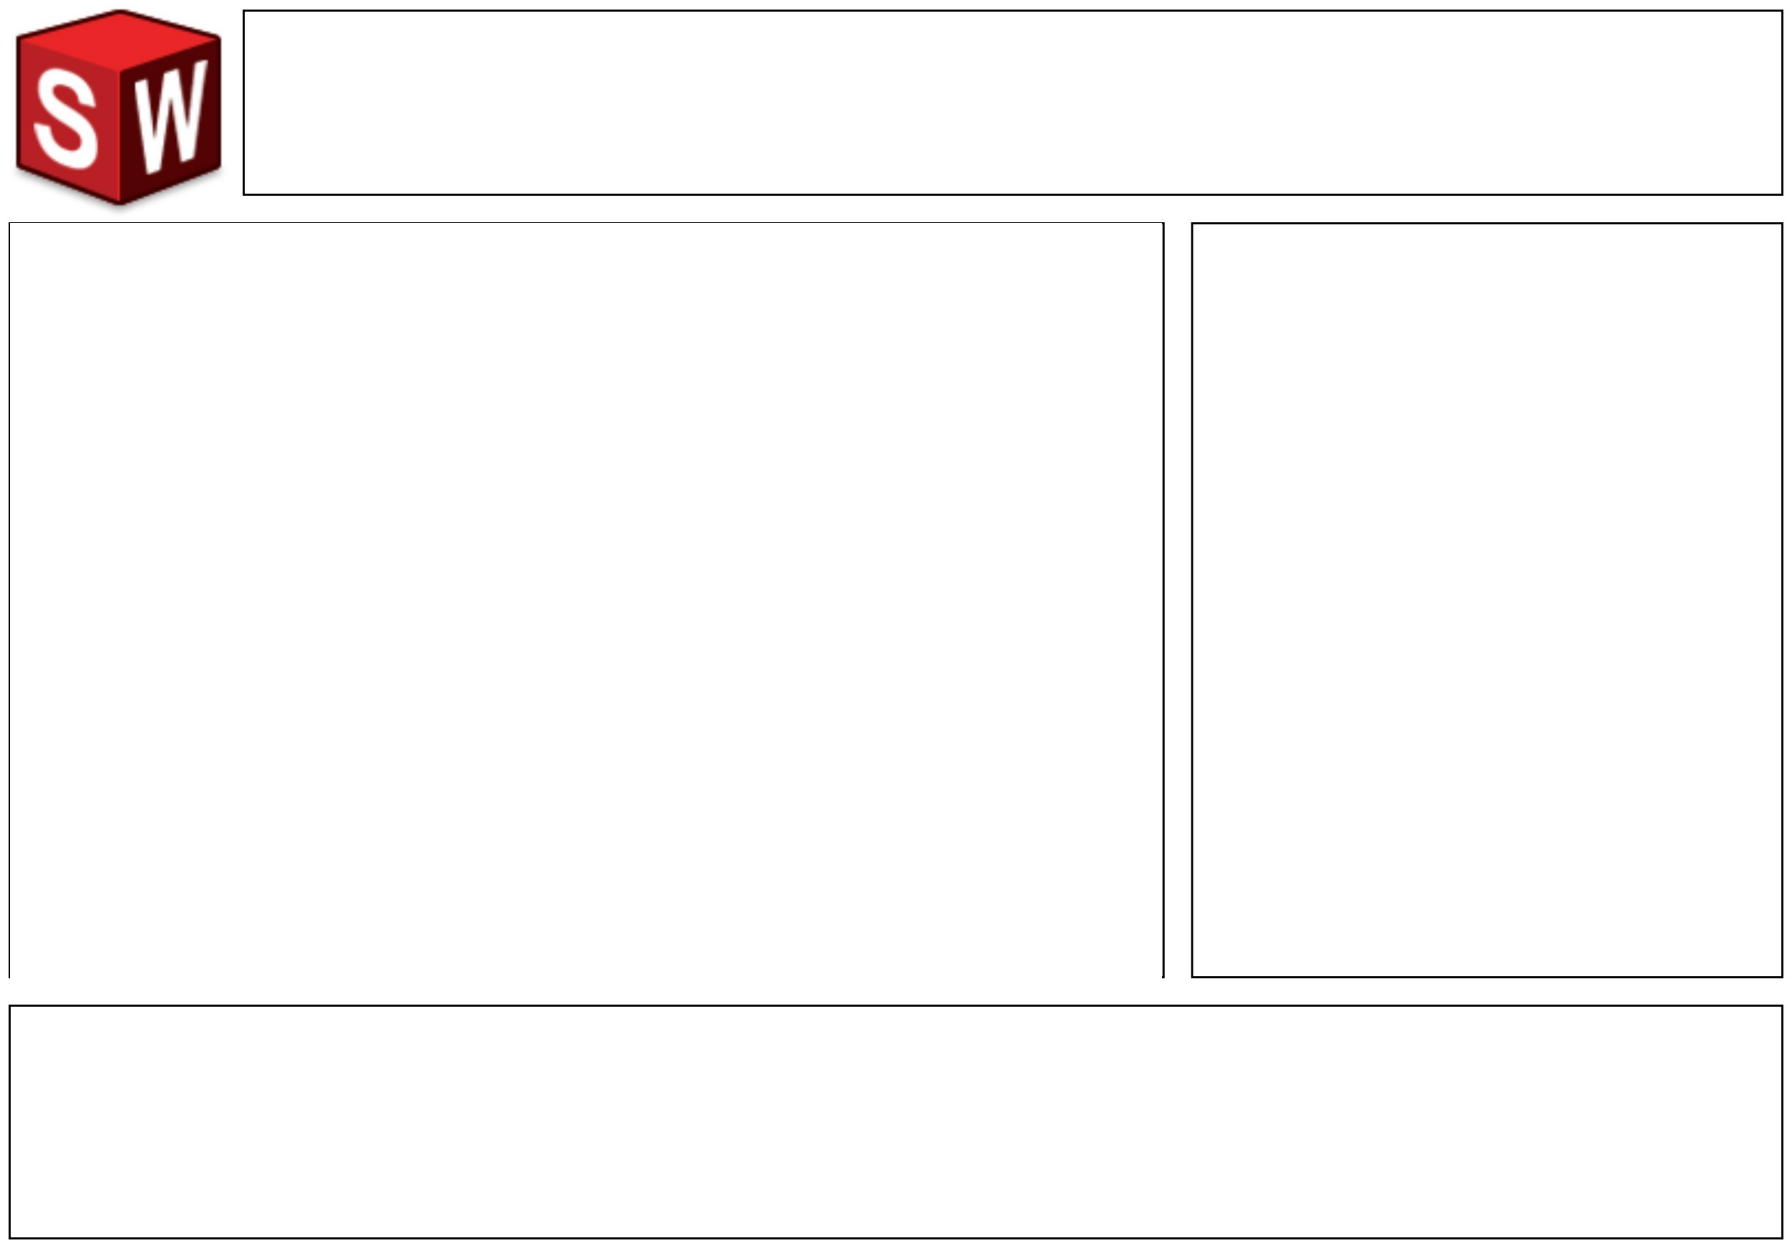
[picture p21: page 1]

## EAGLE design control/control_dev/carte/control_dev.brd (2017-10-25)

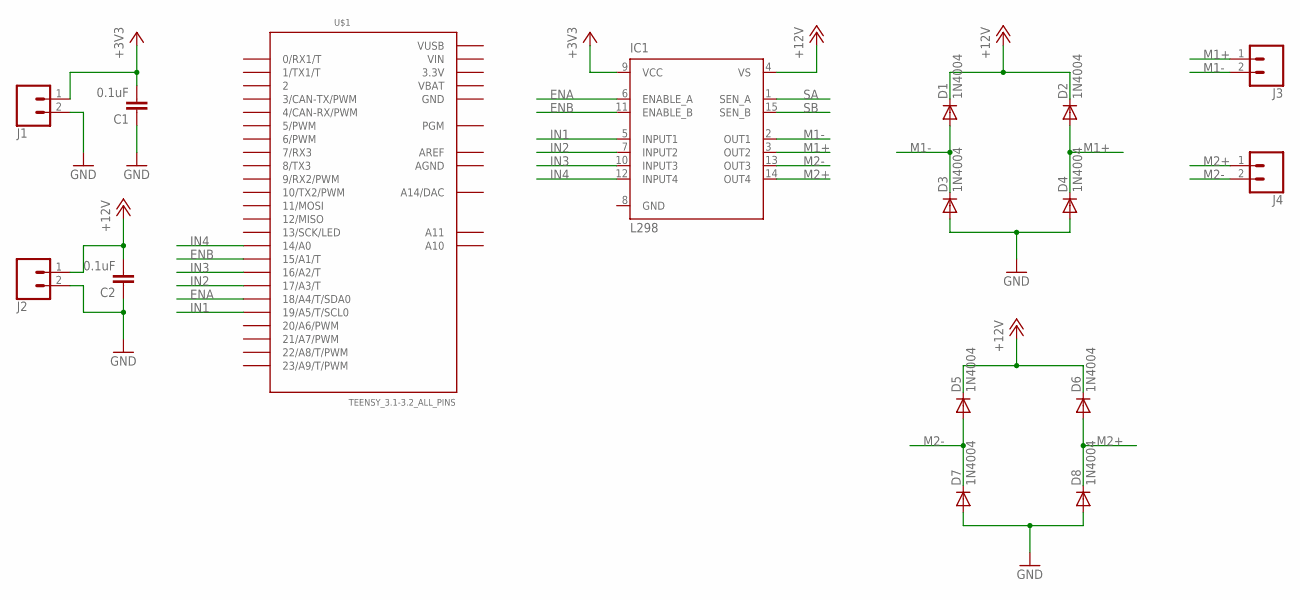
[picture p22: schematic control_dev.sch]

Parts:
C1, C2: 0.1uF; CAP-PTH-SMALL-KIT
D1, D2, D3, D4, D5, D6, D7, D8: 1N4004; DO41-10
IC1: L298; MULTIWATT-15
J1, J2, J3, J4: CONN_023.5MM; SCREWTERMINAL-3.5MM-2
U$1: TEENSY_3.1-3.2_ALL_PINS; TEENSY_3.0-3.2&LC_ALL_PINS

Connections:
3.3V: U$1.3.3V, U$1.3.3V1 (3.3V)
+3V3: C1.2, IC1.9 (VCC), J1.1
+12V: C2.2, D1.C, D2.C, D5.C, D6.C, IC1.4 (VS), J2.1
AGND: U$1.AGND
AREF: U$1.AREF
ENA: IC1.6 (ENABLE_A), U$1.18/A4 (18/A4/T/SDA0)
ENB: IC1.11 (ENABLE_B), U$1.15/A1 (15/A1/T)
GND: C1.1, C2.1, D3.A, D4.A, D7.A, D8.A, IC1.8 (GND), J1.2, J2.2, U$1.GND, U$1.GND1 (GND)
IN1: IC1.5 (INPUT1), U$1.19/A5 (19/A5/T/SCL0)
IN2: IC1.7 (INPUT2), U$1.17/A3 (17/A3/T)
IN3: IC1.10 (INPUT3), U$1.16/A2 (16/A2/T)
IN4: IC1.12 (INPUT4), U$1.14/A0
M1+: D2.A, D4.C, IC1.3 (OUT2), J3.1
M1-: D1.A, D3.C, IC1.2 (OUT1), J3.2
M2+: D6.A, D8.C, IC1.14 (OUT4), J4.1
M2-: D5.A, D7.C, IC1.13 (OUT3), J4.2
SA: IC1.1 (SEN_A)
SB: IC1.15 (SEN_B)
VBAT: U$1.VBAT
VIN: U$1.VIN
VUSB: U$1.VUSB

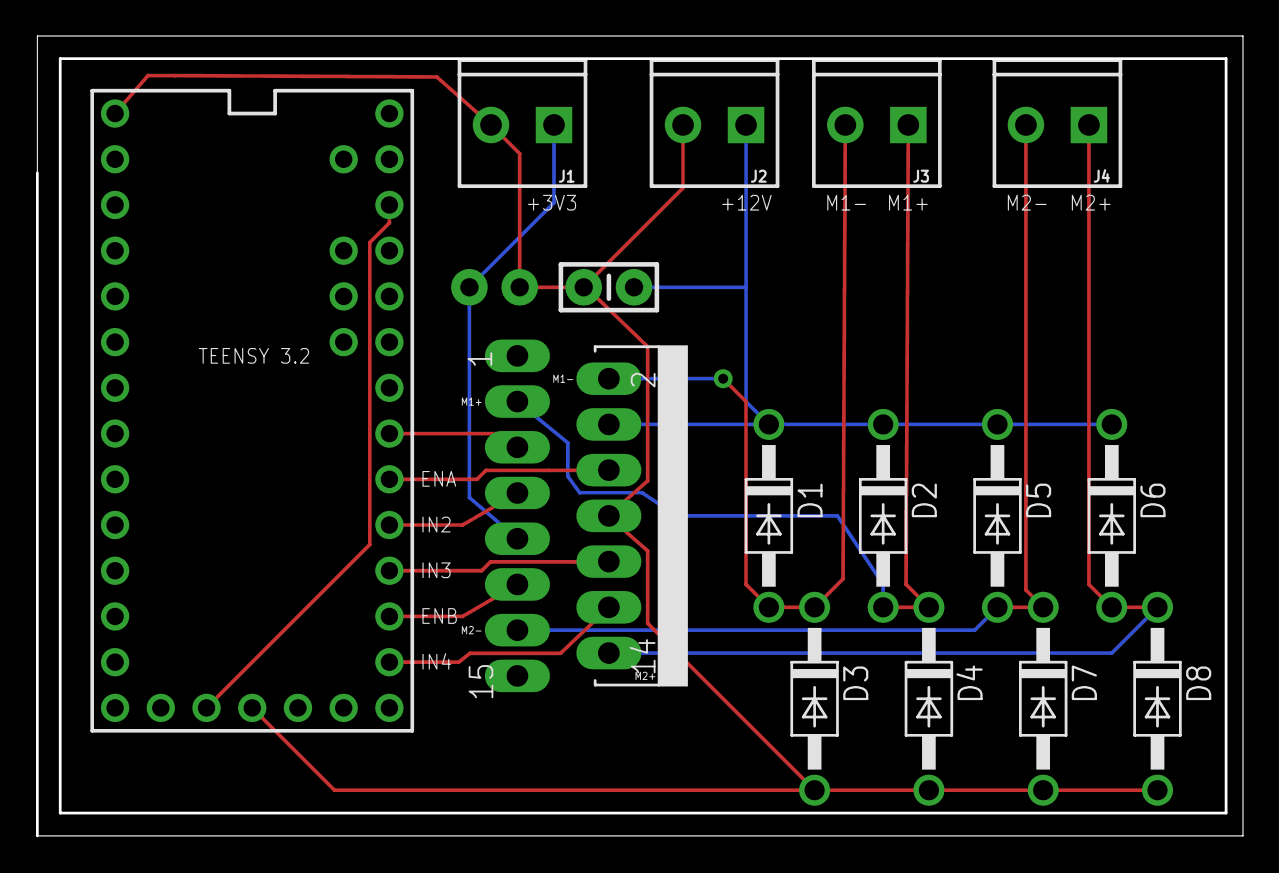
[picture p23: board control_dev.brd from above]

Board: 2 copper layers, 67.0 x 44.4 mm, 16 parts (1 on the bottom side), 14 nets.

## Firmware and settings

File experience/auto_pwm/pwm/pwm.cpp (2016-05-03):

#if ARDUINO >= 100
    #include "Arduino.h"
#else
    #include "WProgram.h"
#endif
const int ledPin=13;
const int pwmPin = 3;
const int startPwm=127;
const int maxPwm=255;
const int minPwm=66;
const int pwmIt=5;
const int tickToKeepPwm=100;
int currentTick=0;
int direction=1;
bool keepPwm=false;
int pwmValue=startPwm;
 
void updatePwm() {
   if(pwmValue!=startPwm) {
   	analogWrite(pwmPin, pwmValue);
   }
}

/*
 * decrement pwmValue if pwmValue is greater than minPwm otherwise we put +1 to the direction
 */
void decrementPwm() {
   if(pwmValue>minPwm) {
   	pwmValue--;
   } else {
   	direction=1;
	keepPwm=true;
   }
}

/**
 * increment pwmValue if pwmValue is lesser than maxPwm otherwise we put -1 to the direction
 */
void incrementPwm() {
   if(pwmValue<maxPwm) {
   	pwmValue++;
   } else {
   	direction=-1;
	keepPwm=true;
   }
}

/**
 * put keepPwm to false when currentTick is greater than tickToKeepPwm 
 */
void waitPwm() {
  if(currentTick<tickToKeepPwm) {
	currentTick++;
  } else {
  	currentTick=0;
	keepPwm=false;
  }

}

/**
 * call depending of the direction either incrementPwm() if 1 or decrementPwm() if -1
 */
void varyPwm() {
   if(!keepPwm) {
	   switch(direction) {
		case 1:
			incrementPwm();
			break;
		case -1:
			decrementPwm();
			break;
		default:
			break;		
	   } 
   } else {
	waitPwm();	
   }
   updatePwm();
}

/**
 * Call varyPwm() and wait 10 milliseconds
 */
void delayPwm() { 
   int i=0;
   while(i<pwmIt) {
   	i++;
	varyPwm();
	delay(10);
   }
}

void setup() { 
   pinMode(pwmPin, OUTPUT);
   pinMode(ledPin, OUTPUT);
   //analogWriteFrequency(pwmPin, 187500);
   //analogWriteFrequency(pwm, 46875);
   Serial.begin(9600);
} 
 
void loop() { 
   digitalWrite(ledPin, HIGH);
   delayPwm();
   digitalWrite(ledPin, LOW);
   delayPwm();
} 

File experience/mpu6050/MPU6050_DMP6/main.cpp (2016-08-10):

// I2C device class (I2Cdev) demonstration Arduino sketch for MPU6050 class using DMP (MotionApps v2.0)
// 6/21/2012 by Jeff Rowberg <jeff@rowberg.net>
// Updates should (hopefully) always be available at https://github.com/jrowberg/i2cdevlib
//
// Changelog:
//      2013-05-08 - added seamless Fastwire support
//                 - added note about gyro calibration
//      2012-06-21 - added note about Arduino 1.0.1 + Leonardo compatibility error
//      2012-06-20 - improved FIFO overflow handling and simplified read process
//      2012-06-19 - completely rearranged DMP initialization code and simplification
//      2012-06-13 - pull gyro and accel data from FIFO packet instead of reading directly
//      2012-06-09 - fix broken FIFO read sequence and change interrupt detection to RISING
//      2012-06-05 - add gravity-compensated initial reference frame acceleration output
//                 - add 3D math helper file to DMP6 example sketch
//                 - add Euler output and Yaw/Pitch/Roll output formats
//      2012-06-04 - remove accel offset clearing for better results (thanks Sungon Lee)
//      2012-06-01 - fixed gyro sensitivity to be 2000 deg/sec instead of 250
//      2012-05-30 - basic DMP initialization working

/* ============================================
I2Cdev device library code is placed under the MIT license
Copyright (c) 2012 Jeff Rowberg

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
THE SOFTWARE IS PROVIDED "AS IS", WITHOUT WARRANTY OF ANY KIND, EXPRESS OR
IMPLIED, INCLUDING BUT NOT LIMITED TO THE WARRANTIES OF MERCHANTABILITY,
FITNESS FOR A PARTICULAR PURPOSE AND NONINFRINGEMENT. IN NO EVENT SHALL THE
AUTHORS OR COPYRIGHT HOLDERS BE LIABLE FOR ANY CLAIM, DAMAGES OR OTHER
LIABILITY, WHETHER IN AN ACTION OF CONTRACT, TORT OR OTHERWISE, ARISING FROM,
OUT OF OR IN CONNECTION WITH THE SOFTWARE OR THE USE OR OTHER DEALINGS IN
THE SOFTWARE.
===============================================
*/

// I2Cdev and MPU6050 must be installed as libraries, or else the .cpp/.h files
// for both classes must be in the include path of your project
#include "I2Cdev.h"

#include "MPU6050_6Axis_MotionApps20.h"
//#include "MPU6050.h" // not necessary if using MotionApps include file

// Arduino Wire library is required if I2Cdev I2CDEV_ARDUINO_WIRE implementation
// is used in I2Cdev.h
#if I2CDEV_IMPLEMENTATION == I2CDEV_ARDUINO_WIRE
    #include "Wire.h"
#endif

// class default I2C address is 0x68
// specific I2C addresses may be passed as a parameter here
// AD0 low = 0x68 (default for SparkFun breakout and InvenSense evaluation board)
// AD0 high = 0x69
MPU6050 mpu;
//MPU6050 mpu(0x69); // <-- use for AD0 high

/* =========================================================================
   NOTE: In addition to connection 3.3v, GND, SDA, and SCL, this sketch
   depends on the MPU-6050's INT pin being connected to the Arduino's
   external interrupt #0 pin. On the Arduino Uno and Mega 2560, this is
   digital I/O pin 2.
 * ========================================================================= */

/* =========================================================================
   NOTE: Arduino v1.0.1 with the Leonardo board generates a compile error
   when using Serial.write(buf, len). The Teapot output uses this method.
   The solution requires a modification to the Arduino USBAPI.h file, which
   is fortunately simple, but annoying. This will be fixed in the next IDE
   release. For more info, see these links:

   http://arduino.cc/forum/index.php/topic,109987.0.html
   http://code.google.com/p/arduino/issues/detail?id=958
 * ========================================================================= */



// uncomment "OUTPUT_READABLE_QUATERNION" if you want to see the actual
// quaternion components in a [w, x, y, z] format (not best for parsing
// on a remote host such as Processing or something though)
//#define OUTPUT_READABLE_QUATERNION

// uncomment "OUTPUT_READABLE_EULER" if you want to see Euler angles
// (in degrees) calculated from the quaternions coming from the FIFO.
// Note that Euler angles suffer from gimbal lock (for more info, see
// http://en.wikipedia.org/wiki/Gimbal_lock)
#define OUTPUT_READABLE_EULER

// uncomment "OUTPUT_READABLE_YAWPITCHROLL" if you want to see the yaw/
// pitch/roll angles (in degrees) calculated from the quaternions coming
// from the FIFO. Note this also requires gravity vector calculations.
// Also note that yaw/pitch/roll angles suffer from gimbal lock (for
// more info, see: http://en.wikipedia.org/wiki/Gimbal_lock)
//#define OUTPUT_READABLE_YAWPITCHROLL

// uncomment "OUTPUT_READABLE_REALACCEL" if you want to see acceleration
// components with gravity removed. This acceleration reference frame is
// not compensated for orientation, so +X is always +X according to the
// sensor, just without the effects of gravity. If you want acceleration
// compensated for orientation, us OUTPUT_READABLE_WORLDACCEL instead.
//#define OUTPUT_READABLE_REALACCEL

// uncomment "OUTPUT_READABLE_WORLDACCEL" if you want to see acceleration
// components with gravity removed and adjusted for the world frame of
// reference (yaw is relative to initial orientation, since no magnetometer
// is present in this case). Could be quite handy in some cases.
//#define OUTPUT_READABLE_WORLDACCEL

// uncomment "OUTPUT_TEAPOT" if you want output that matches the
// format used for the InvenSense teapot demo
//#define OUTPUT_TEAPOT



#define INTERRUPT_PIN 2  // use pin 2 on Arduino Uno & most boards
#define LED_PIN 13 // (Arduino is 13, Teensy is 11, Teensy++ is 6)
bool blinkState = false;

// MPU control/status vars
bool dmpReady = false;  // set true if DMP init was successful
uint8_t mpuIntStatus;   // holds actual interrupt status byte from MPU
uint8_t devStatus;      // return status after each device operation (0 = success, !0 = error)
uint16_t packetSize;    // expected DMP packet size (default is 42 bytes)
uint16_t fifoCount;     // count of all bytes currently in FIFO
uint8_t fifoBuffer[64]; // FIFO storage buffer

// orientation/motion vars
Quaternion q;           // [w, x, y, z]         quaternion container
VectorInt16 aa;         // [x, y, z]            accel sensor measurements
VectorInt16 aaReal;     // [x, y, z]            gravity-free accel sensor measurements
VectorInt16 aaWorld;    // [x, y, z]            world-frame accel sensor measurements
VectorFloat gravity;    // [x, y, z]            gravity vector
float euler[3];         // [psi, theta, phi]    Euler angle container
float ypr[3];           // [yaw, pitch, roll]   yaw/pitch/roll container and gravity vector

// packet structure for InvenSense teapot demo
uint8_t teapotPacket[14] = { '$', 0x02, 0,0, 0,0, 0,0, 0,0, 0x00, 0x00, '\r', '\n' };



// ================================================================
// ===               INTERRUPT DETECTION ROUTINE                ===
// ================================================================
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

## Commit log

2016-01-30 ajout des pieces solidwors
    [plaque160-80-2.SLDPRT]
2016-01-30 conception mecanique de marvin 1
    [carte.SLDPRT, fixationMoteur40-2.SLDPRT, jante10-2.SLDPRT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]
2016-02-18 ajout de marvin
    [marvinTete.SLDPRT]
2016-02-22 ajout de la tete de marvin sous solidworks
2016-02-25 Ajout d'un programme de test qui est produit grace a CMAKE.
2016-02-25 Enrichissement du README.md pour ajouter des explications sur l'installation de l'environement.
2016-03-02 Ajout de nouveaux tests + correction cmake (upload et librairies).
    [servo.cpp]
2016-03-02 Maj de la documentation par rapport à cmake et l'upload.
2016-03-06 ajout du fichier tex décrivant les besoins de Marvin
2016-03-07 ajout du cours d'élec basé sur les vidéos de Thonain
2016-03-07 correction comprenant pour que les références vers la courbe se fassent correctement
2016-03-16 Ajout du programme de pilotage du potentiometre numerique.
2016-04-19 Ajout d'un test de pwm avec écran LCD.
2016-04-26 Ajout de CMake pour latex
2016-05-03 Ajout d'un programme qui augmente et diminue automatiquement une pwm sur la pin 3 de la teensy pour ajuster la vitesse du moteur sur un circuit de puissance
2016-05-03 Ajustement de Arduino.cmake pour qu'il utilise teensy_loader_cli au lieu de teensy pour déployer sur la teensy directement
2016-05-03 ajout du script d'installation teensy_loader_cli pour la compatibilité avec le nouveau build cmake
2016-05-03 Ajout d'un paragraphe de description pour installation de la commande teensy_loader_cli
2016-05-17 Mise a jour de la documentation pour les transistors MOFSET
2016-05-17 Ajout doc (partiel) sur le driver de mofset.
2016-05-31 Ajout de quelques chapitre à compléter et mise à jour du CMake pour la gestion de bibtex
2016-07-06 Ajout d'un programme de visualisation gyroscopic OpenGL
2016-08-09 application OpenGL pour observer le comportement du capteur IMU5066
2016-08-09 Ajout des librairie d'utilisation du MPU6050 compilé avec cmake
2016-08-09 ajout du fichier bibtex pour la bibliographie
2016-08-09 renommage de setup en configure
2016-08-09 ajout du dépot de gestion des ports series
2016-08-09 mise à jour de configure
2016-08-09 Ajout du sous module pour les ports séries
2016-08-10 modification des valeurs offset initiales du gyroscrope Ajout d'un README.md pour utiliser le gyroscope Modification du dépot serial pour une integration plus facile
2016-08-10 Ajout du svg teensy
2016-12-20 Mise en gconf de la partie vhdl
2016-12-20 Ajout de l'environement de test.
2016-12-20 Correctionde l'environement de simulation du decodeur
2017-01-16 Ajout du code vhdl qui fait la gestion memeoire des servomoteur + script
2017-01-31 Ajout du module servomoteur, avec l environement de simultation associé
2017-01-31 Ajout du dirvers avec des consignes en angle de 0 a 180 deg
2017-01-31 Ajout du module en charge des IO
2017-03-28 Ajout de la datasheet du composant ADC sur 12bit, avec 8 channels
2017-05-03 Update gyroscopic README.md
2017-05-16 passage de test_blink avec la nouvelle toolchain
2017-05-16 Passage de test_pwm avec la nouvelle toolchains
2017-05-16 Portage de testServo
2017-05-16 Mise à jour de la toolchain auto_pwm
2017-05-16 mise à jour de mpu6050
2017-05-16 Modification de l'arborescence de MarvinWay
2017-05-16 Vrai push de l'arborescence
2017-05-23 Ajout du projet d'exemple pour teensy
2017-10-25 Ajout du design de la carte de control de développement
    [control_dev.brd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]
2017-11-01 Ajout de la documentation concernant le pont en H

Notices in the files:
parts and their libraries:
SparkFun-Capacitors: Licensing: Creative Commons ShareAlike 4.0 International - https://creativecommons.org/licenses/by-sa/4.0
